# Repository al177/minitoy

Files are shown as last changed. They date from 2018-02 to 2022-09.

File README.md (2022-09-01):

Dead-end personal project for a WiFi enabled FPGA board using the Lattice ICE40UP5K FPGA.

Features:

- Minimal-ish part count due to using the ESP8266 to configure the FPGA during power-up
- Intended to run Micropython
- Fast SPI channel between ICE40 and ES8266 can be used as a communications channel after boot

This project has been built as of the 0.1 revision of the PCB. There are numerous workarounds needed to get it running that are
rolled up into the v0.2 PCB committed here, though v0.2 has not been manufactured.

Possible improvements:

- ESP32 instead of ESP8266 for an additional serial port for a separate console, additional horsepower, and lower power modes.
- Reset button
- Combine both 3.3v LDOs since I don't think sequencing 1.2 before 3.3 is that critical for the ICE40
- Fix RGB LED pinout
- Fix reset circuit for ESP (in v0.2)
- 0 ohm resistor to take 5v power from FTDI cable
- LiFePO4 or LiPo power

Included are iceboot.py, a Micropython module that can boot an ICE40 bitstream, and boot.py which is a startup script to load a
bitstream on Micropython power-up.

*** If you wish to use iceboot.py with modern Micropython, please use the currently maintained version here: https://github.com/al177/blinkencard/blob/master/micropython/iceboot.py . The version here is specific to an old version of the LoBoris fork, and the machine API for SPI has changed since.

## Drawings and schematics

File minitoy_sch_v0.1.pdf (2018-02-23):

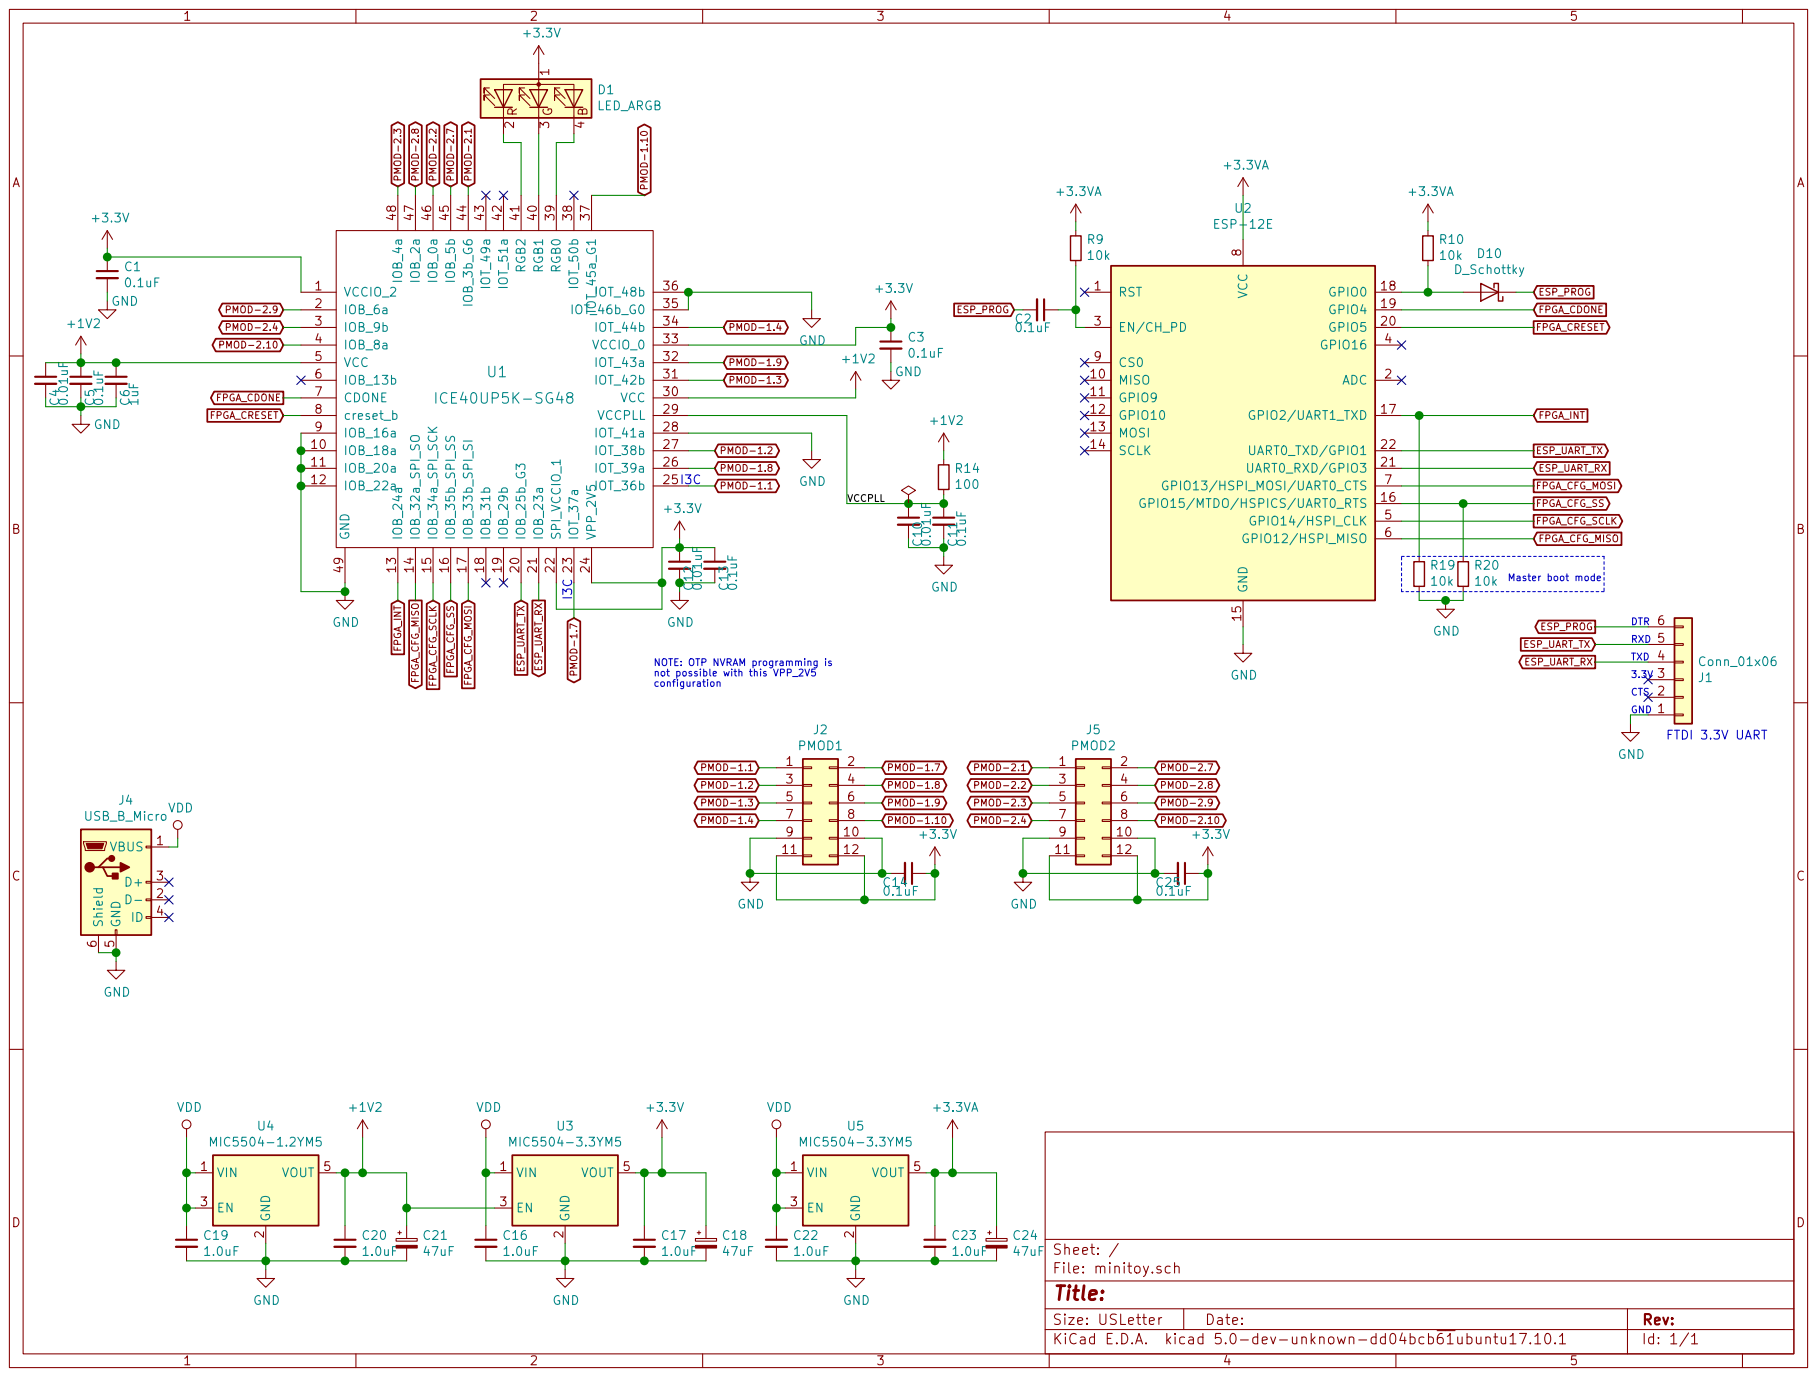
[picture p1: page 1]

NOTE: OTP NVRAM programming is not possible with this VPP_2V5

2 EN 3 VOUT 5 U4 MIC5504-1.2YM5 VDD +1V2 VDD +3.3V GND GND

2 EN 3 VOUT 5 U5 MIC5504-3.3YM5 VDD GND

2 EN 3 VOUT 5 U3 MIC5504-3.3YM5 VIN 1 GND

File: minitoy.sch Sheet: /

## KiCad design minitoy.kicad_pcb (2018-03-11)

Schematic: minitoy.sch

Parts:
C1, C3, C5, C11, C13, C14, C25: 0.1uF; C_0603_HandSoldering
C2, C6: 1uF; C_0603_HandSoldering
C4, C10, C12: 0.01uF; C_0603_HandSoldering
C16, C17, C19, C20, C22, C23: 1.0uF; C_0603_HandSoldering
C18, C21, C24: 47uF; CP_Elec_5x5.3
D1: LED_ARGB; LED_Cree-PLCC4_3.2x2.8mm_CCW
D10: D_Schottky; D_SOD-123
J1: Conn_01x06; Pin_Header_Straight_1x06_Pitch2.54mm
J2: PMOD1; Socket_Strip_Angled_2x06_Pitch2.54mm
J4: USB_B_Micro; USB_Micro-B_10103594-0001LF
J5: PMOD2; Socket_Strip_Angled_2x06_Pitch2.54mm
R1, R9, R10, R19, R20: 10k; R_0603_HandSoldering
R14: 100; R_0603_HandSoldering
U1: ICE40UP5K-SG48; QFN-48-1EP_7x7mm_Pitch0.5mm
U2: ESP-12E
U3, U5: MIC5504-3.3YM5; SOT-23-5_HandSoldering
U4: MIC5504-1.2YM5; SOT-23-5_HandSoldering

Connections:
+1V2: C4.1, C5.1, C6.1, C20.1, C21.1, R14.2, U1.5, U1.30, U3.3, U4.5 (VOUT)
+3.3VA: C23.1, C24.1, R1.2, R9.2, R10.2, R19.2, U2.8, U5.5
+3V3: C1.1, C3.1, C12.1, C13.1, C14.1, C17.1, C18.1, C25.1, D1.1, J2.11, J2.12, J5.11, J5.12, U1.1, U1.22, U1.24, U1.33, U3.5
/VCCPLL: C10.1, C11.1, R14.1, U1.29
ESP_PROG: C2.2, D10.1, J1.6
ESP_UART_RX: J1.4, U1.21, U2.21
ESP_UART_TX: J1.5, U1.20, U2.22
FPGA_CDONE: U1.7, U2.19
FPGA_CFG_MISO: U1.14, U2.6
FPGA_CFG_MOSI: U1.17, U2.7
FPGA_CFG_SCLK: U1.15, U2.5
FPGA_CFG_SS: R20.2, U1.16, U2.16
FPGA_CRESET: U1.8, U2.20
FPGA_INT: R19.1, U1.13, U2.17
GND: C1.2, C3.2, C4.2, C5.2, C6.2, C10.2, C11.2, C12.2, C13.2, C14.2, C16.2, C17.2, C18.2, C19.2, C20.2, C21.2, C22.2, C23.2, C24.2, C25.2, J1.1, J2.9, J2.10, J4.5, J4.6, J5.9, J5.10, R20.1, U1.9, U1.10, U1.11, U1.12, U1.28, U1.35, U1.36, U1.49, U2.15, U3.2, U4.2 (GND), U5.2
unnamed: C2.1, R9.1, U2.1
unnamed: D1.2, U1.41
unnamed: D1.3, U1.40
unnamed: D1.4, U1.39
unnamed: D10.2, R10.1, U2.18
unnamed: R1.1, U2.3
PMOD-1.1: J2.1, U1.25
PMOD-1.2: J2.3, U1.27
PMOD-1.3: J2.5, U1.31
PMOD-1.4: J2.7, U1.34
PMOD-1.7: J2.2, U1.23
PMOD-1.8: J2.4, U1.26
PMOD-1.9: J2.6, U1.32
PMOD-1.10: J2.8, U1.37
PMOD-2.1: J5.1, U1.44
PMOD-2.2: J5.3, U1.46
PMOD-2.3: J5.5, U1.48
PMOD-2.4: J5.7, U1.3
PMOD-2.7: J5.2, U1.45
PMOD-2.8: J5.4, U1.47
PMOD-2.9: J5.6, U1.2
PMOD-2.10: J5.8, U1.4
VDD: C16.1, C19.1, C22.1, J4.1, U3.1, U4.1 (VIN), U4.3 (EN), U5.1, U5.3

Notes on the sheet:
NOTE: OTP NVRAM programming is not possible with this VPP_2V5 configuration
I3C
FTDI 3.3V UART
DTR
TXD
RXD
GND
CTS

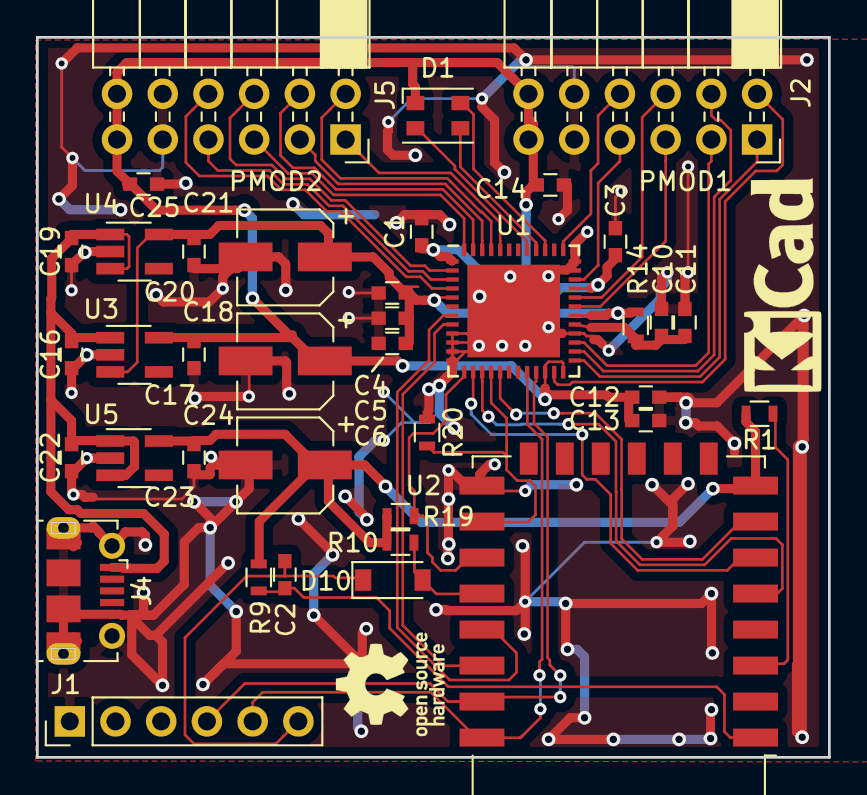
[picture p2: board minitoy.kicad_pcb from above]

Board: 2 copper layers, 44.0 x 40.0 mm, 38 parts (0 on the bottom side), 38 nets.

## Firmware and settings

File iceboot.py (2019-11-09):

import machine
import os
import time


def boot(binfile):
    creset=machine.Pin(5,machine.Pin.OUT, machine.Pin.PULL_UP)
    cdone=machine.Pin(4,machine.Pin.IN, machine.Pin.PULL_UP)
    ss=machine.Pin(15,machine.Pin.OUT, machine.Pin.PULL_UP)
    s=machine.SPI(1,polarity=1,phase=1,baudrate=10000000)

    creset.off()
    ss.off()
    time.sleep(1)
    creset.on()
    print(cdone.value())
    time.sleep(1)
    with open(binfile,'rb') as f:
        b=f.read(32)
        while b:
            b=f.read(32)
            s.write(b)
    print(cdone.value())
    bytecnt=0
    while bytecnt < 20:
        bytecnt+=1
        s.write(b'X')
    print(bytecnt)
    ss.on()
    print(cdone.value())

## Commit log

2018-02-16 Initial import - work in progress
    [minitoy.kicad_pcb, minitoy.sch]
2018-02-17 Change ESP reset scheme and UART connection
    [minitoy.sch]
2018-02-18 Rough schematic complete.
    [minitoy.sch]
2018-02-19 Start layout
    [minitoy.kicad_pcb, minitoy.sch]
2018-02-19 Remove blinkenlights and buttons, add another PMOD socket
    [minitoy.kicad_pcb, minitoy.sch]
2018-02-19 More consolidation of the board
    [minitoy.kicad_pcb, minitoy.sch]
2018-02-20 More layout changes, remove a PMOD socket for easier routing
    [minitoy.kicad_pcb, minitoy.sch]
2018-02-22 Routing done, but cleanup needed
    [minitoy.kicad_pcb, minitoy.sch]
2018-02-22 Routing complete. Next up, fix silk.
    [minitoy.kicad_pcb]
2018-02-22 Fix 3d models, change USB footprint
    [minitoy.kicad_pcb]
2018-02-23 Finish silk, fix USB cutout for OSH Park, finalize design
    [minitoy.kicad_pcb]
2018-02-23 Generate gerbers, RTM
2018-02-23 Last minute fix for possible short
    [minitoy.kicad_pcb]
2018-03-11 v0.2: fix ESP POR straps and reset, fix typo on serial connector
    [minitoy.kicad_pcb, minitoy.sch]
